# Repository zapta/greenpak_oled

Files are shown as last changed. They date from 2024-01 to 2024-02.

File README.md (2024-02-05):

# Addressable SPI OLED display

This design demonstrates the technique of adding device addressing capabilities to a SPI bus. This provides the speed and distance of an SPI bus with the simplicity and extensibility of an I2C bus.

The addressability is achieved using a Renesas's GreenPAK SPLD devices which interprets the first byte of each SPI transaction as a meta control byte and passes the CS signal to the device only if the address encoded in the control byte matches the device's address. The supported OLED displays are 1.3" SSD1306 and SH1106. 

> **NOTE**: The SSD1306 and the SH1106 are compatible at the hardware level but require different software drivers.

Resources
* PCB schematic: https://github.com/zapta/greenpak_oled/blob/main/kicad/greenpak_oled.pdf
* GreenPAK design schematic: https://github.com/zapta/greenpak_oled/blob/main/greenpak/greenpak_oled.svg
* GreenPAK source and hex files: https://github.com/zapta/greenpak_oled/tree/main/greenpak
* Interactive BOM: https://htmlpreview.github.io/?https://github.com/zapta/greenpak_oled/blob/main/kicad/bom/ibom.html

<br>

Components side:

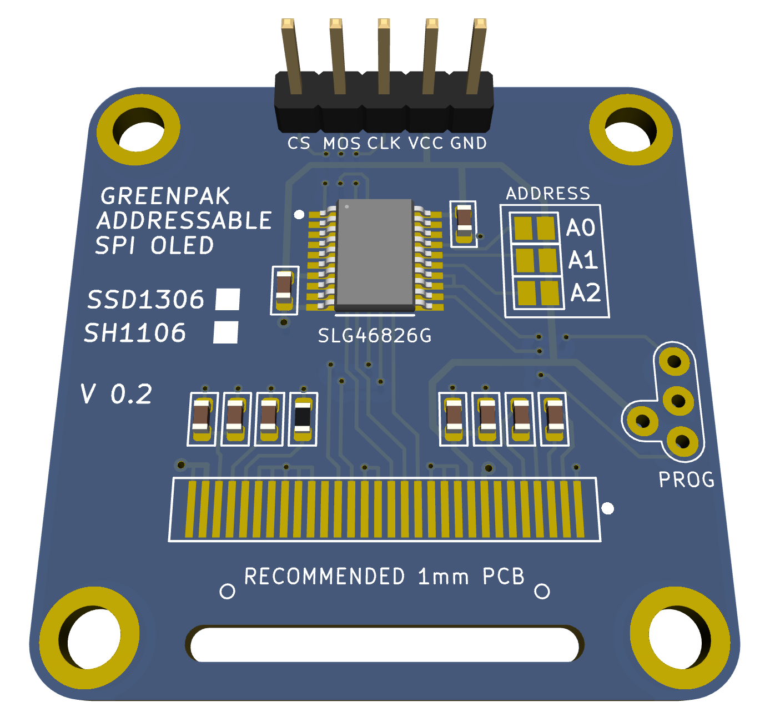
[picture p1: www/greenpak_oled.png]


<br>

Display panel side:

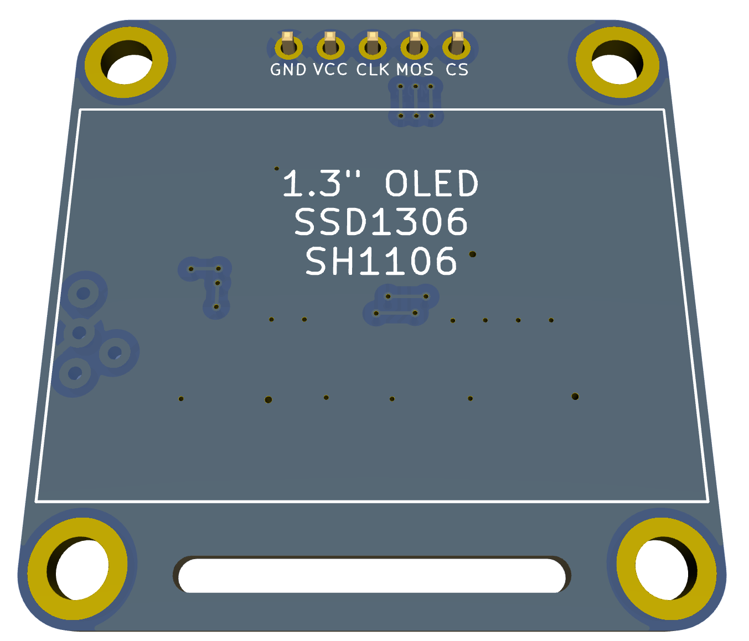
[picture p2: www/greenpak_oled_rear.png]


<br>

Wiring diagram (for oled_demo.py):

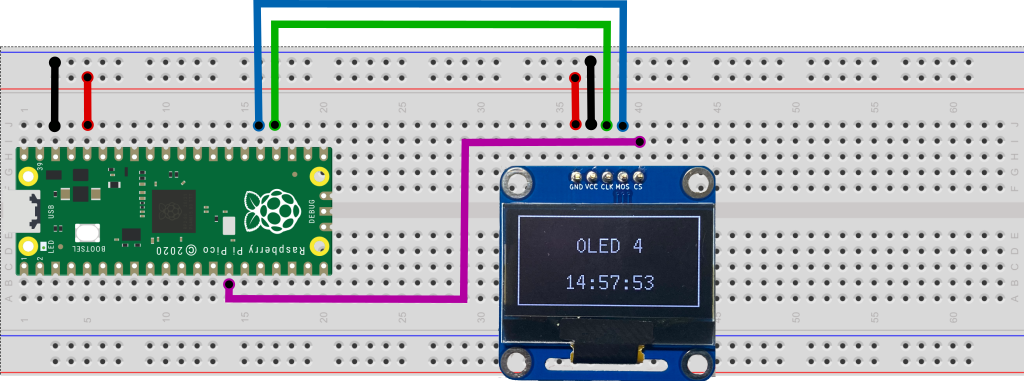
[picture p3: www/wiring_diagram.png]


## Protocol

A SPI transaction is a sequence of bytes transfer between a high-to-low and a low-to-high transitions of the ``CS`` signal. To tag a transaction with a device address, prepend to it a control byte which include the target device address as well as the desired states of the OLED ``RST`` and ``DC`` inputs.

| Bit field | Function | Description |
|---|---|---|
| Bits [7:5] |  Reserved | Set to 0. |
| Bits [4:4] |  RST | The value of the OLED RST input. |
| Bits [3:4] |  DC | The value of the OLED D/C input  |
| Bits [2:1] |  Address | The target device address in the range [0, 7] |

The address of each device is set by its three solder jumbers, with an open jumper
representing ``0`` and short jumper representing ``1``

## Device SPI address

The device address is set by shorting with solder the necessary solder jumpers according to this table:

|Address | A1 | A1 | A0 |
|:---:|:---:|:---:|:----:|
| 0 |  - |  - |  - |
| 1 |  - |  - |  Solder |
| 2 |  - | Solder | -  |
| 3 |  - | Solder | Solder  |
| 4 | Solder |  - | -  |
| 5 | Solder |  - |  Solder |
| 6 | Solder | Soler | -  |
| 7 | Solder | Solder | Solder  |

## oled_demo.py

The Python program demo_oled.py demonstrates the addressability by continuously writing a different content to each of the eight possible device addresses. Connecting one or more 
device will display on each a number that identify it's address. The demo uses a USB to SPI adapter, such as a plain Raspberry Pi Pico, that is compatible with the  Python package ``spi-adapter``.

## Timing diagrams

The screenshot below shows a typical address enabled SPI transaction. The first byte 
is the control byte ``0x12`` contains the signals ``OLED_RST=1``, ``OLED_DC=0``, and is ``ADDRESS=2``, and is matched against the device address, which happens to be 2,  and causes a match. This sets the ``OLED_RST`` and ``OLED_DC`` outputs to their respective values (no change in the case of ``OLED_RST``) and then enables ``OLED_CS`` such that the rest of the bytes are processed by the OLED device.

<br>

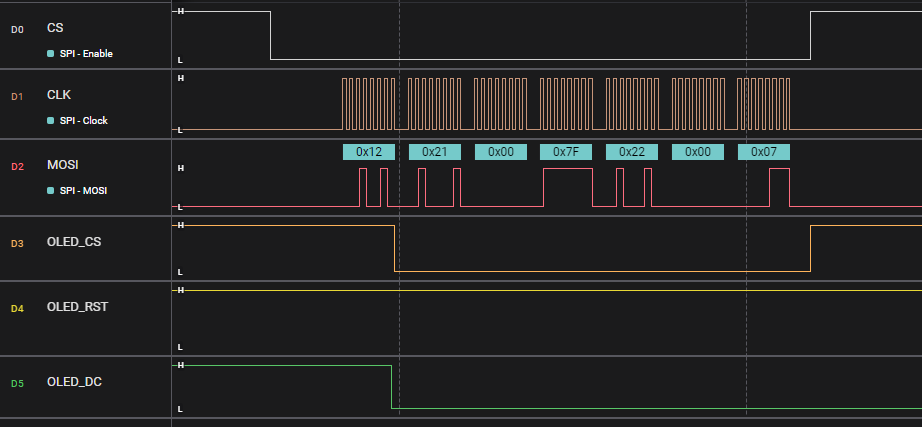
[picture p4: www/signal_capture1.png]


The following diagram zoom on the control byte. Note that the ``OLED_DC`` (and so ``OLED_RST`` when changed) stabilizes on its new level before  ``OLED_CS`` is asserted low.

<br>

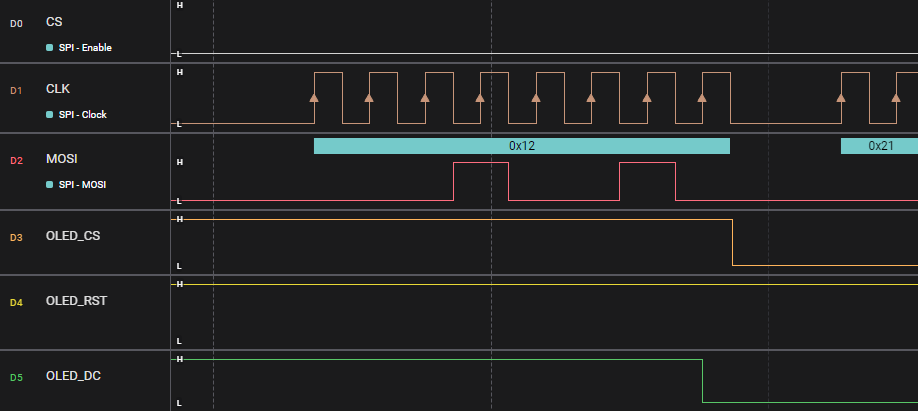
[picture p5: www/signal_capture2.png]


## How it works?

The diagram below shows the main functional blocks of the GreenPAK design. For full details and the latest version, explore the design file ``greenpak_oled.gp6`` file using the Renesas design tool.

1. I2C programming support. Used only for flashing or reflashing the GreenPAK device and is not used in normal operation.
2. Serial to parallel shifter. A shift register that provides the four previous SPI bit values.
3. First byte detector. Generates signal that indicates the time of the 8'th bit of the control byte (the first byte in the SPI transaction)
4. Address matcher. On the last bit of the control byte, tests if the address matches.
5. OLED_CS generator. A latch that generates the the ``OLED_CS`` output signals.
6. Auxiliary signals generators. Latches for the ``OLED_RST`` and ``OLED_DC`` output signals.
  
<br>



## Making your own

To make your own Addressable SPI OLED display follow these steps:

1. Order the PCB and components.
1. Assemble the components, including the OLED panel which is soldered to the 30 pags strip.
1. Program the GreenPAK device as described below.
1. Set the display address on the SPI bus by soldering the necessary solder jumpers.

The Github repository contains an HTML interactive BOM that helps identifying the components and their values.

## Flashing the GreenPAK

Flashing the GreenPAK IC can be done in-circuit via the programming pads which are compatible with the [GreenPAK Pogo Probe](https://github.com/zapta/greenpak_pogo). The provided Python program ``flasher.py`` allows to program it using an USB to I2C adapter such as the Raspberry Pi Pico, or the Sparkfun Pro Micro RP2040. which are supported by the Python ``i2c_adapter`` package. 

## FAQ

Q: What is the operating voltage of the OLED display.

A: 3.3V nominal.

---

Q: What SPI mode is used?

A: SPI mode 0 as required by the SSD1306 and SH1106 controllers.

---

Q: What SPI speeds are supported?

A: We tested it successfully with 4Mhz SPI clock.

---

Q: Why only 3 address jumpers?

A: We run out of resources in the GreenPAK device. 

---

Q: I want to change the design of the GreenPAK device, what tools do I need?

A: The Go Configure tool is available for free from Renesas and it allows to edit and test GreenPAK designs.  https://www.renesas.com/us/en/software-tool/go-configure-software-hub

---

Q: Why GreenPAK?

A: They are inexpensive, stand alone, flexible, have a small footprint, not requiring glue components.

---

Q: What kind of a guarantee do you provide with this design?

A: None whatsoever, the design is provided 'as-is'.

---

Q: This design doesn't uses MISO. Is it possible have MISO reading with addressable SPI?

A: Yes. A MISO signal can be used without having to change the GreenPAK's design.

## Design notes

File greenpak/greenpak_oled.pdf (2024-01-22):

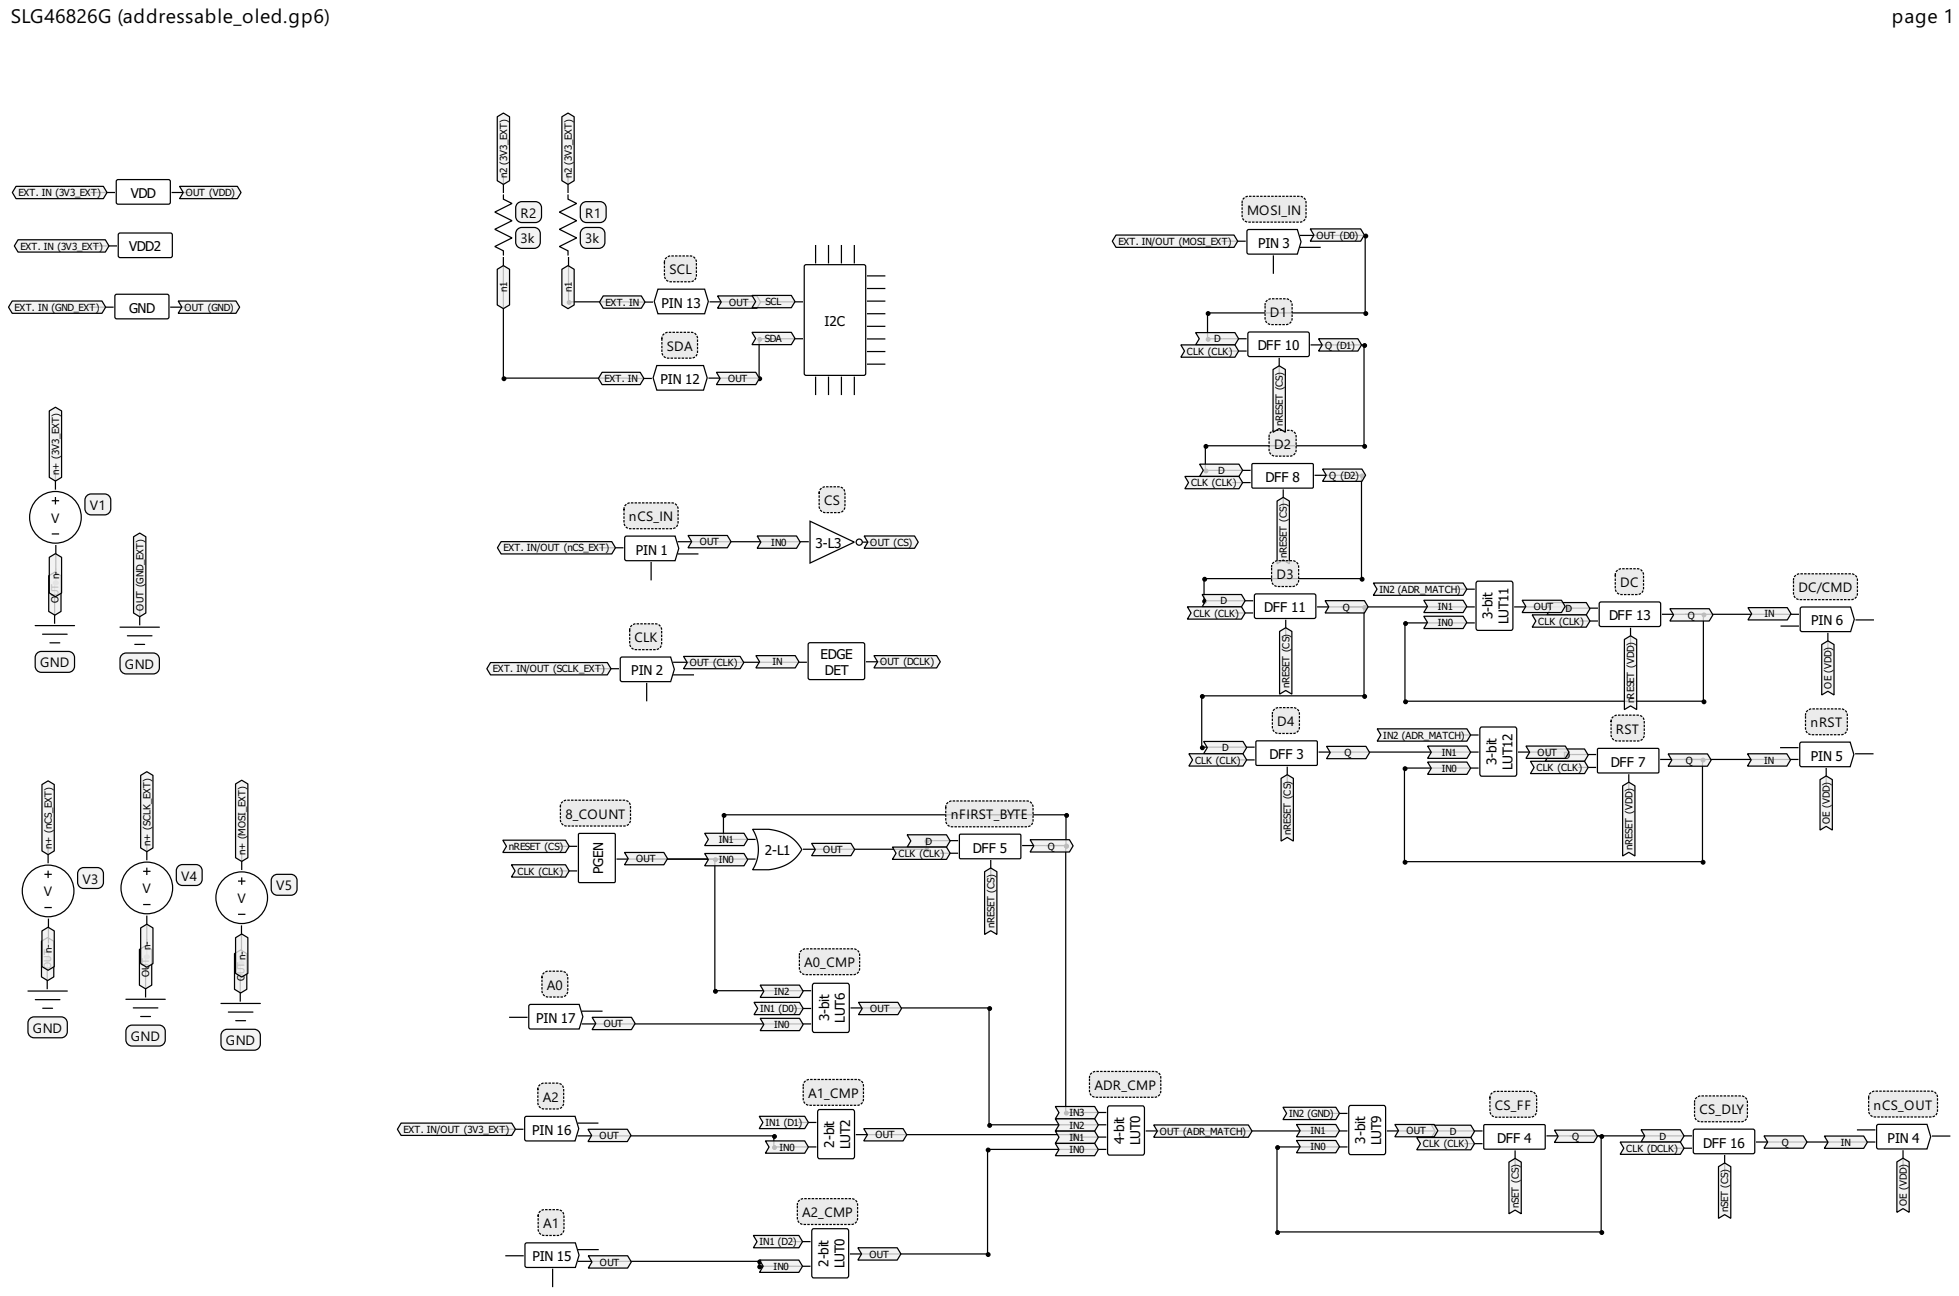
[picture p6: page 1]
SLG46826G (addressable_oled.gp6); page 1; EXT. IN; PIN 13; OUT; SCL; SDA; PIN 12; EXT. IN (GND_EXT); GND; OUT (GND); EXT. IN (3V3_EXT); VDD2; VDD; OUT (VDD); OUT PIN 17; EXT. IN/OUT (3V3_EXT); PIN 16; OUT PIN 15; OE (VDD); PIN 6; DC/CMD; PIN 5; nRST; PIN 4; nCS_OUT; OUT (D0) EXT. IN/OUT (MOSI_EXT); PIN 3; MOSI_IN; OUT (CLK) EXT. IN/OUT (SCLK_EXT); PIN 2; CLK; EXT. IN/OUT (nCS_EXT); PIN 1; nCS_IN; OUT (DCLK) EDGE; DET; OUT 2⁻bit; LUT0; A2_CMP; LUT2; A1_CMP; nRESET (CS); CLK (CLK); PGEN; 8_COUNT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
P rty rop e | Va l u e
alu Min. v e ( V) | 3.1 0

Ty
p. v

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
x. v

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
P rop e rty | l Va u
| Digital input In mode Digital in with Schmit e I/O selection

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
ull D
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
P rop e rty | l Va u
e I/O selection | Digital input In mode | Digital in with Schmit

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
ull D
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
P rop e rty | l Va u
| Digital input In mode Digital in with Schmit e I/O selection

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
ull D
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
e I/O selection | Digital input In mode | Digital in without Sch

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
P rop e rty | l Va u
e I/O selection | Digital input In mode | Digital in without Sch

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
P rty rop e | Va l u e
alu Min. v e ( V) | 3.1 0
Ty alu ( V) p. v e | 3.3 0

M
a
x. v

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
e I/O selection | Digital output In mode | None Out mode | 1x push pull PIN 5 (IO10) Label: "nRST" Property | Value I/O selection | Digital output In mode | None Out mode | 1x push pull | P

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
e I/O selection | Digital output In mode | None Out mode | 1x push pull PIN 3 (IO12) Label: "MOSI_IN" Property | Value I/O selection | Digital input In mode | Digital in with Schmit

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
ull D
o

w

n
R sis t alu e o r v e | 1 0 0 K

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
P rop e rty | l Va u
e I/O selection | Digital input In mode | Digital in with Schmit

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
ull D
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
P rop e rty | l Va u
e I/O selection | Digital input In mode | Digital in with Schmit

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
ull U
p
R sis t alu e o r v e | 1 0 0 K
1 0 0 u A p ullu p o n in p u t | Dis a ble

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
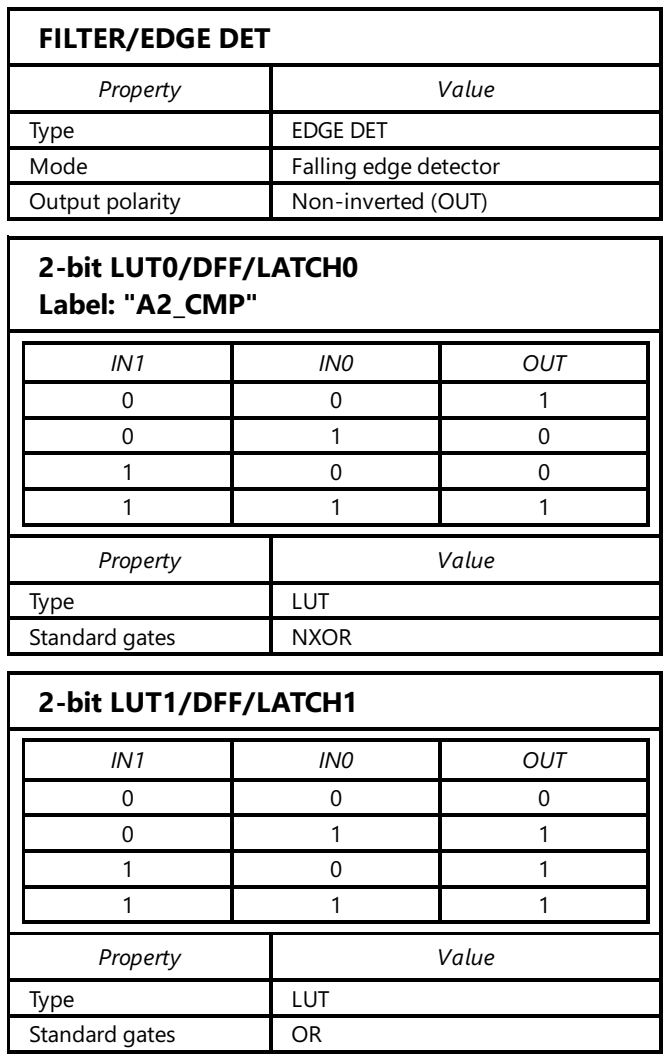
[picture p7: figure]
P rty rop e; allin; ola rit y; ATC H; rop; rty; P rop e rty

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
### ATC

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
P rop e rty | Va l u e
Ty p e | L U T

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
6 : 0

P t t a e r n | 0 0 0 0 0 0 1

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
### ATC

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
P rop e rty | l Va u e

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
d ele S e c o n Q s c t | f fir Q o s t D F F

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
T Initial polarity | Low Q output polarity | Non-in

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
### ATC

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
P rty rop e | Va l u e

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
T Initial polarity | High Q output polarity | Non-in

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
### ATC

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
M d o e | D F F
S E T/ R E S E T tio n n o p n | R E S E n
| Low Q output polarity Non-in T Initial polarity

d v e r t e ( Q)

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
### ATC

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
I N 0 | O U T
0 | 1
1 | 0
P rop e rty | Va l u e

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
s | In
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
### ATC

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
P rop e rty | l Va u e
Ty p e | D F F / L ATC H
M o d e | D F F
n S E T/ n R E S E T o p tio n | n R E S E
| Low Q output polarity Non-in T Initial polarity
| t Q) v

### 3-bit LUT5/DFF/LATCH8 Label: "D2"

Property | Value
Type | DFF / LATCH
Mode | DFF
nSET/nRESET option | nRESET
Initial polarity | Low
Q output polarity | Non-inverted (Q)

### 3-bit LUT6/Pipe Delay/Ripple Counter Label: "A0_CMP"

IN2 | IN1 | IN0 | OUT
0 | 0 | 0 | 0
0 | 0 | 1 | 0
0 | 1 | 0 | 0
0 | 1 | 1 | 0
1 | 0 | 0 | 1
1 | 0 | 1 | 0
1 | 1 | 0 | 1
1 | 1 | 1 | 0
Property | Value
Type | LUT
Standard gates | Defined by user

### MF0 (4-bit LUT0, DFF/LATCH9, WS Ctrl, 16-bit CNT0/DLY0/FSM0)

### 4-bit LUT0 (MF0) Label: "ADR_CMP"

IN3 | IN2 | IN1 | IN0 | OUT
0 | 0 | 0 | 0 | 0
0 | 0 | 0 | 1 | 0
0 | 0 | 1 | 0 | 0
0 | 0 | 1 | 1 | 0
0 | 1 | 0 | 0 | 0
0 | 1 | 0 | 1 | 0
0 | 1 | 1 | 0 | 0
0 | 1 | 1 | 1 | 1
1 | 0 | 0 | 0 | 0
1 | 0 | 0 | 1 | 0
1 | 0 | 1 | 0 | 0
1 | 0 | 1 | 1 | 0
1 | 1 | 0 | 0 | 0
1 | 1 | 0 | 1 | 0
1 | 1 | 1 | 0 | 0
1 | 1 | 1 | 1 | 0
Property | Value
Standard gates | Defined by user

### MF1 (3-bit LUT7, DFF/LATCH10, 8-bit CNT1/ DLY1)

### DFF/LATCH10 (MF1) Label: "D1"

Property | Value
Mode | DFF
nSET/nRESET option | nRESET
Initial polarity | Low
Q output polarity | Non-inverted (Q)

### MF2 (3-bit LUT8, DFF/LATCH11, 8-bit CNT2/ DLY2)

### DFF/LATCH11 (MF2) Label: "D3"

Property | Value
Mode | DFF
nSET/nRESET option | nRESET
Initial polarity | Low
Q output polarity | | Non-inverted (Q)

### MF3 (3-bit LUT9, DFF/LATCH12, 8-bit CNT3/ DLY3)

### 3-bit LUT9 (MF3)

IN2 | IN1 | IN0 | OUT
0 | 0 | 0 | 0
0 | 0 | 1 | 1
0 | 1 | 0 | 0
0 | 1 | 1 | 0
1 | 0 | 0 | 0
1 | 0 | 1 | 1
1 | 1 | 0 | 0
1 | 1 | 1 | 0
Property | Value
Standard gates | Defined by user

### MF4 (3-bit LUT10, DFF/LATCH13, 8-bit CNT4/ DLY4)

### DFF/LATCH13 (MF4) Label: "DC"

Property | Value
Mode | DFF
nSET/nRESET option | nRESET
Initial polarity | Low
Q output polarity | Non-inverted (Q)
SLG46826G (addressable_oled.gp6) | page 4

### MF5 (3-bit LUT11, DFF/LATCH14, 8-bit CNT5/ DLY5)

### 3-bit LUT11 (MF5)

IN2 | IN1 | IN0 | OUT
0 | 0 | 0 | 0
0 | 0 | 1 | 1
0 | 1 | 0 | 0
0 | 1 | 1 | 1
1 | 0 | 0 | 0
1 | 0 | 1 | 0
1 | 1 | 0 | 1
1 | 1 | 1 | 1
Property | Value
Standard gates | Defined by user

### MF6 (3-bit LUT12, DFF/LATCH15, 8-bit CNT6/ DLY6)

### 3-bit LUT12 (MF6)

IN2 | IN1 | IN0 | OUT
0 | 0 | 0 | 0
0 | 0 | 1 | 1
0 | 1 | 0 | 0
0 | 1 | 1 | 1
1 | 0 | 0 | 0
1 | 0 | 1 | 0
1 | 1 | 0 | 1
1 | 1 | 1 | 1
Property | Value
Standard gates | Defined by user

### MF7 (3-bit LUT13, DFF/LATCH16, 8-bit CNT7/ DLY7)

### DFF/LATCH16 (MF7) Label: "CS_DLY"

Property | Value
Mode | DFF
nSET/nRESET option | nSET
Initial polarity | High
Q output polarity | Non-inverted (Q)

I2C

Property | Value
IO Latching | Enable
Mode selection | Standard/fast mode
Control code, bin | 0001
Control byte, read/ write | 0x11 / 0x10

Device address, dec/
hex

8 / 0x08

PIN 19 (IO0) output
expander select

From matrix

PIN 14 (IO5) output expander select | From matrix
PIN 11 (IO6) output expander select | From matrix
PIN 6 (IO9) output expander select | From matrix
Virtual OUT0 | 0
Virtual OUT1 | 0
Virtual OUT2 | 0
Virtual OUT3 | 0
Virtual OUT4 | 0
Virtual OUT5 | 0
Virtual OUT6 | 0
Virtual OUT7 | 0
PIN 19 (IO0) OUT | 0
PIN 14 (IO5) OUT | 0
PIN 11 (IO6) OUT | 0
PIN 6 (IO9) OUT | 0

Control code selection
#3 | #2 | #1 | #0

0 | 0 | 0 | 1
SLG46826G (addressable_oled.gp6) | page 5

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
Volt
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
s Internal capacitance | 10
0 n
F Internal resistance | 10Ohm Pre-start state | Low Type | DC DC Voltage | 3.3V Ramp rise time | 1ms V3 Property

Va

l
u

e

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
p la
s

t
s

t
a

t
e
Ty p e | L gic o p a t t e r n
M d o e | N o r m
| 3.3V Umin 0V Levels adjustment Standar al Umax
| d
Ris tim e e | 1 μ s
F all tim e | 1 μ s

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
2 5 0 μ s | 3.3 V
2 5 0 μ s | 0 V

2
5

0
μ

s

3.3
V
2 5 0 μ s | 0 V
2 5 0 μ s | 3.3 V
2 5 0 μ s | 0 V

2
5

0
μ

s

3.3
V
2 5 0 μ s | 0 V
2 5 0 μ s | 3.3 V

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
2 5 0 μ s | 0 V
2 5 0 μ s | 3.3 V
2 5 0 μ s | 0 V
2 5 0 μ s | 3.3 V
2 5 0 μ s | 0 V
2 5 0 μ s | 3.3 V
2 5 0 μ s | 0 V
2 5 0 μ s | 3.3 V

2
5

0
μ

s

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
D u ra t i o n | l Vo t a g e
5 0 0 μ s | 3.3 V
5 0 0 μ s | 0 V
5 0 0 μ s | 0 V
5 0 0 μ s | 3.3 V
5 0 0 μ s | 3.3 V
5 0 0 μ s | 0 V
5 0 0 μ s | 3.3 V
5 0 0 μ s | 0 V
5 0 0 μ s | 0 V
5 0 0 μ s | 3.3 V
5 0 0 μ s | 3.3 V
5 0 0 μ s | 3.3 V
5 0 0 μ s | 0 V
5 0 0 μ s | 3.3 V
5 0 0 μ s | 3.3 V

P

oj
c

t
c

M

i
n. | Typ. | M
a
x. VDD (V): | 3.10 | 3.30 | 3.40 VDD2 (V): | 3.10 | 3.30 | 3.40 Temperature (°C): | 25.00 | 25.00 | 25.00 General Settings GPIO quick charge | Disable Pattern ID | 1 2k Register lock status | Unlocked 2k NVM lock status | Unlocked Emulated EEPROM lock status | Unlocked Protect entire lock configuration | Disable

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
X: 0
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
C: 1

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
X: 0
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
C: 1

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
X: 0
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
C: 1

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
X: 0
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
C: 1

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
X: 0
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
C: 1

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
X: 0
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
C: 1

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
X: 0
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
C: 1

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
X: 0
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
C: 1

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
X: 0
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
C: 1

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
X: 0
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
C: 1

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
X: 0
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
C: 1

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
X: 0
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
C: 1

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
X: 0
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
C: 1

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
X: 0
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
C: 1

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
X: 0
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
C: 1

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
X: 0
x

`
b
D

E

C: 1

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
X: 0
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
C: 1

1
8

`
b
0

+

2 bit L U T 3 / P G E N --> O U T | N E T 2 8 | H E X: 0 7 6 ` b 1 x D E C: 1 1 8 ` b 1 | +
3 bit L U T 0/ D F F / -L ATC H 3 Q -> | N E T 3 5 | H E X: 0 7 6 ` b 2 x D E C: 1 1 8 ` b 2 | +
3 bit L U T 1 / D F F / -L ATC H 4 Q -> | C S O U T n _ | H E X: 0 7 6 ` b 3 x D E C: 1 1 8 ` b 3 | +
3 bit L U T 2 / D F F / -L ATC H 5 Q -> | N E T 2 9 | H E X: 0 7 6 ` b 4 x D E C: 1 1 8 ` b 4 | +
3 bit L U T 3 / D F F / -L ATC H 6 O U T -> | C S | H E X: 0 7 6 ` b 5 x D E C: 1 1 8 ` b 5 | +
3 bit L U T 4/ D F F / -L ATC H 7 Q -> | N E T 3 4 | H E X: 0 7 6 ` b 6 x D E C: 1 1 8 ` b 6 | +
3 bit L U T 5 / D F F / -L ATC H 8 Q -> | D 2 | H E X: 0 7 6 ` b 7 x D E C: 1 1 8 ` b 7 | +
3 bit L U T 6/ Pip -e D ela / Rip ple C t y o u n e r -> O U T | N E T 2 3 | H E X: 0 7 7 ` b 0 x D E C: 1 1 9 ` b 0 | +
3 bit L U T 6/ Pip -e D ela y / Rip ple C o u n t e r -> Q 1 | | H E X: 0 7 7 ` b 1 x D E C: 1 1 9 ` b 1 | -
3 -bit L U T 6/ Pip e ela ple D y / Rip C o u n t e r Q 2 -> | | H E X: 0 x 7 7 ` b 2 ` b D E C: 1 1 9 2 | -
FILT E R/ E D G E D E T -> O U T | D C L K | ` b H E X: 0 x 7 7 3 D E C: 1 1 9 ` b 3 | +
P D LY -> O U T | | ` b H E X: 0 x 7 7 4 D E C: 1 1 9 ` b 4 | -
bit 8 -C N T 1 / D LY 1 ( M F 1 ) O U T -> | | ` b H E X: 0 x 7 7 5 D E C: 1 1 9 ` b 5 | -
O S C 1 -> O U T 0 | | ` b H E X: 0 x 7 7 6 D E C: 1 1 9 ` b 6 | -
O C -> O U T | | ` b H E X: 0 x | -

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
C: 1

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
X: 0
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
C: 1
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
X: 0
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
C: 1
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
X: 0
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
C: 1
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
X: 0
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
C: 1
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
X: 0
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
C: 1
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
X: 0
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
C: 1
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
X: 0
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
C: 1
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
X: 0
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
C: 1
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
X: 0
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
C: 1
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
X: 0
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
C: 1
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
X: 0
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
C: 1
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
X: 0
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
C: 1
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
X: 0
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
C: 1
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
X: 0
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
C: 1
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
X: 0
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
C: 1
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
X: 0
x

`
b
D

E

C: 1

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
s I2C -> OUT7

H

E

X: 0
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
C: 1
2

2

`
b
0
- I2C -> OUT6 | HEX: 0x7A`b1 DEC: 122`b1 | - I2C -> OUT5 | HEX: 0x7A`b2 DEC: 122`b2 | - I2C -> OUT4 | HEX: 0x7A`b3 DEC: 122`b3 | - I2C -> OUT3 | HEX: 0x7A`b4 DEC: 122`b4 | - I2C -> OUT2 | HEX: 0x7A`b5 DEC: 122`b5 | - I2C -> OUT1 | HEX: 0x7A`b6 DEC: 122`b6 | - I2C -> OUT0 | HEX: 0x7A`b7 DEC: 122`b7 | -
A C M P 0 H O U T -> | | H E X: 0 7 B ` b 0 x D E C: 1 2 3 ` b 0 | -
A C M P 1 H O U T -> | | H E X: 0 7 B ` b 1 x D E C: 1 2 3 ` b 1 | -
A C M P 2 L O U T -> | | H E X: 0 7 B ` b 2 x D E C: 1 2 3 ` b 2 | -
A C M P 3 L O U T -> | | H E X: 0 7 B ` b 3 x D E C: 1 2 3 ` b 3 | -
O S C 1 O U T 1 -> | | H E X: 0 7 B ` b 4 x D E C: 1 2 3 ` b 4 | -
O S C 0 O U T 1 -> | | H E X: 0 7 B ` b 5 x D E C: 1 2 3 ` b 5 | -
P O R O U T -> | | H E X: 0 7 B ` b 6 x D E C: 1 2 3 ` b 6 | -
V D D ( PIN 2 0 ) O U T -> | V D D | H E X: 0 7 B ` b 7 x D E C: 1 2 3 ` b 7 | +

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
bit 1 6 -C N T 0/ D LY 0/ F S M 0 ( M F 0 ) | d C o u n t e D a t a | H E X: 0 x 7 C , 0 x 7 D D E C: 1 2 4 1 2 5 ,
bit 8 -C N T 2 / D LY 2 ( M F 2 ) | d C o u n t e D a t a | H E X: 0 x 7 E D E C: 126
bit 8 -C N T 4/ D LY 4 ( M F 4 ) | d C o u n t e D a t a | H E X: 0 x 7 F D E C: 127

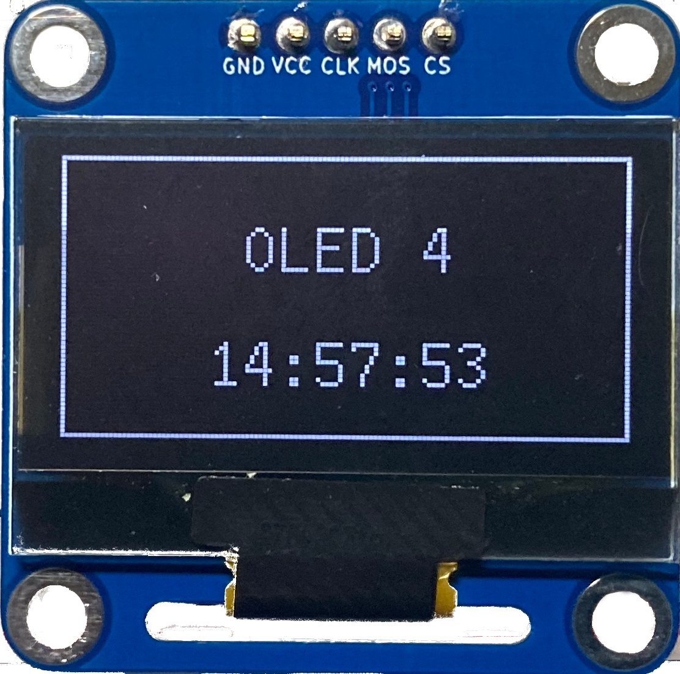
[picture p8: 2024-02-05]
www/spi_oled_pic.png

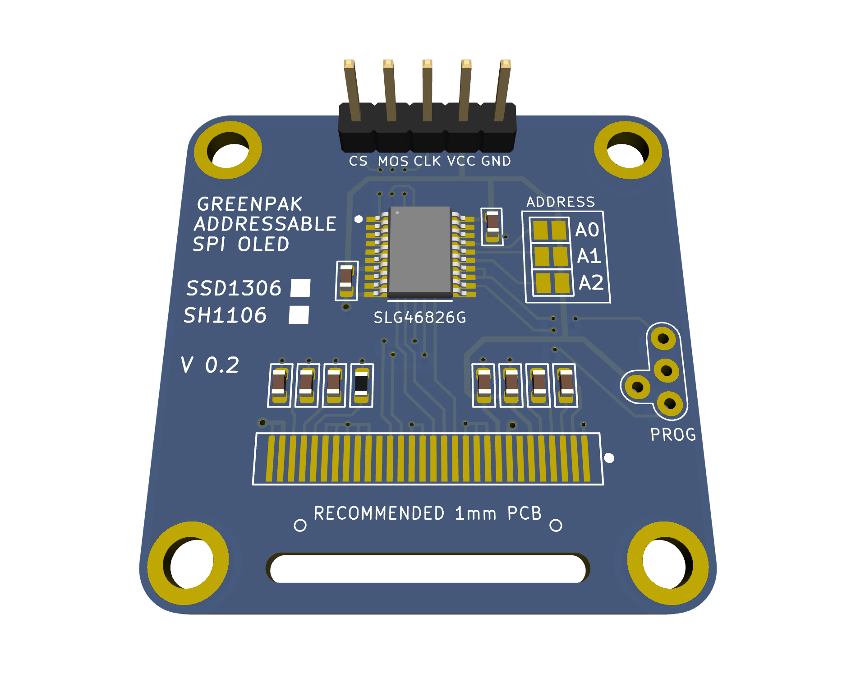
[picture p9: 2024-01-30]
kicad/greenpak_oled.png

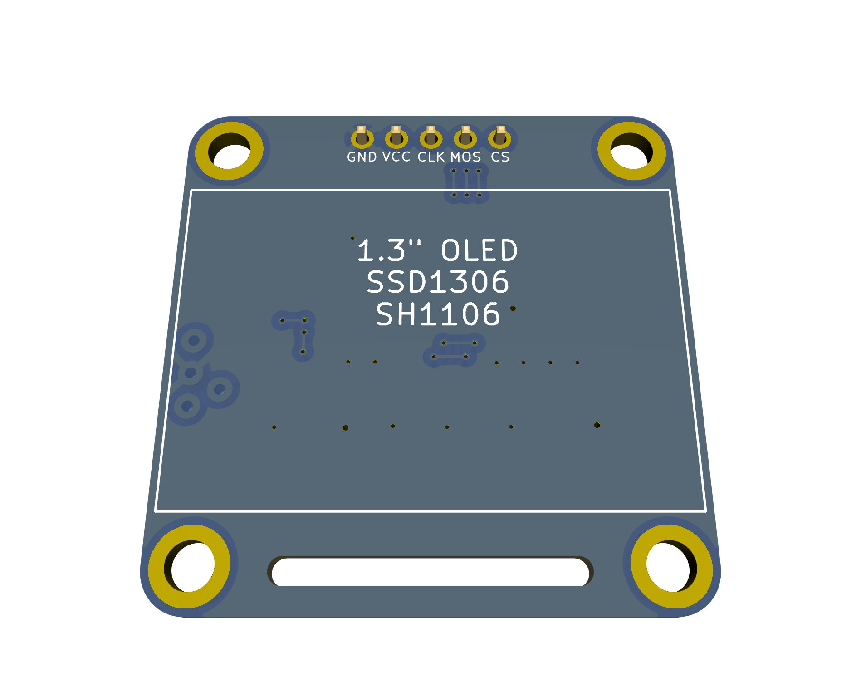
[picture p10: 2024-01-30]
kicad/greenpak_oled_rear.png

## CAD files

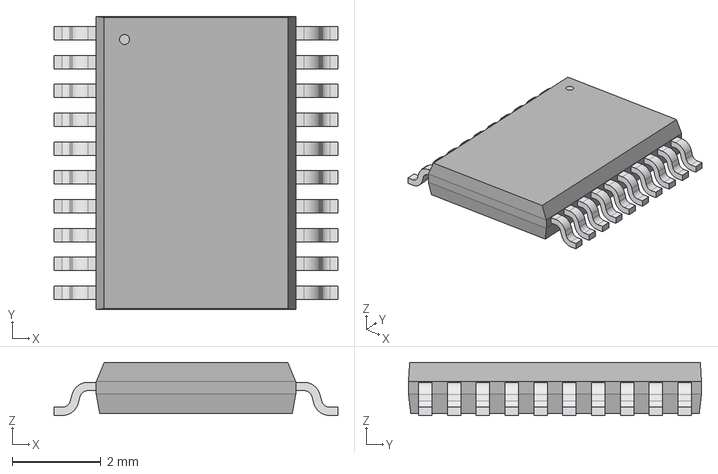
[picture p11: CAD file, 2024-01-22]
kicad/3d_models/TSSOP20_MO-220_WECE_REN.step
6.40 x 6.60 x 1.20 mm

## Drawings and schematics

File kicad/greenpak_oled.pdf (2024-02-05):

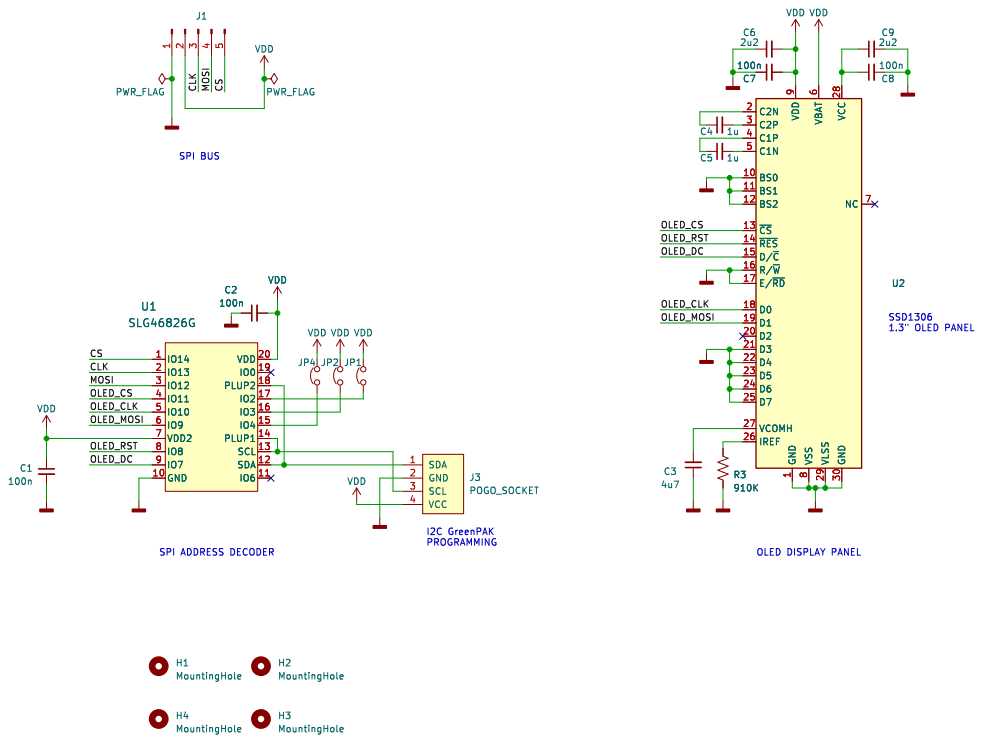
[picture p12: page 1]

1.3" OLED PANEL SPI ADDRESS DECODER U1 SLG46826G

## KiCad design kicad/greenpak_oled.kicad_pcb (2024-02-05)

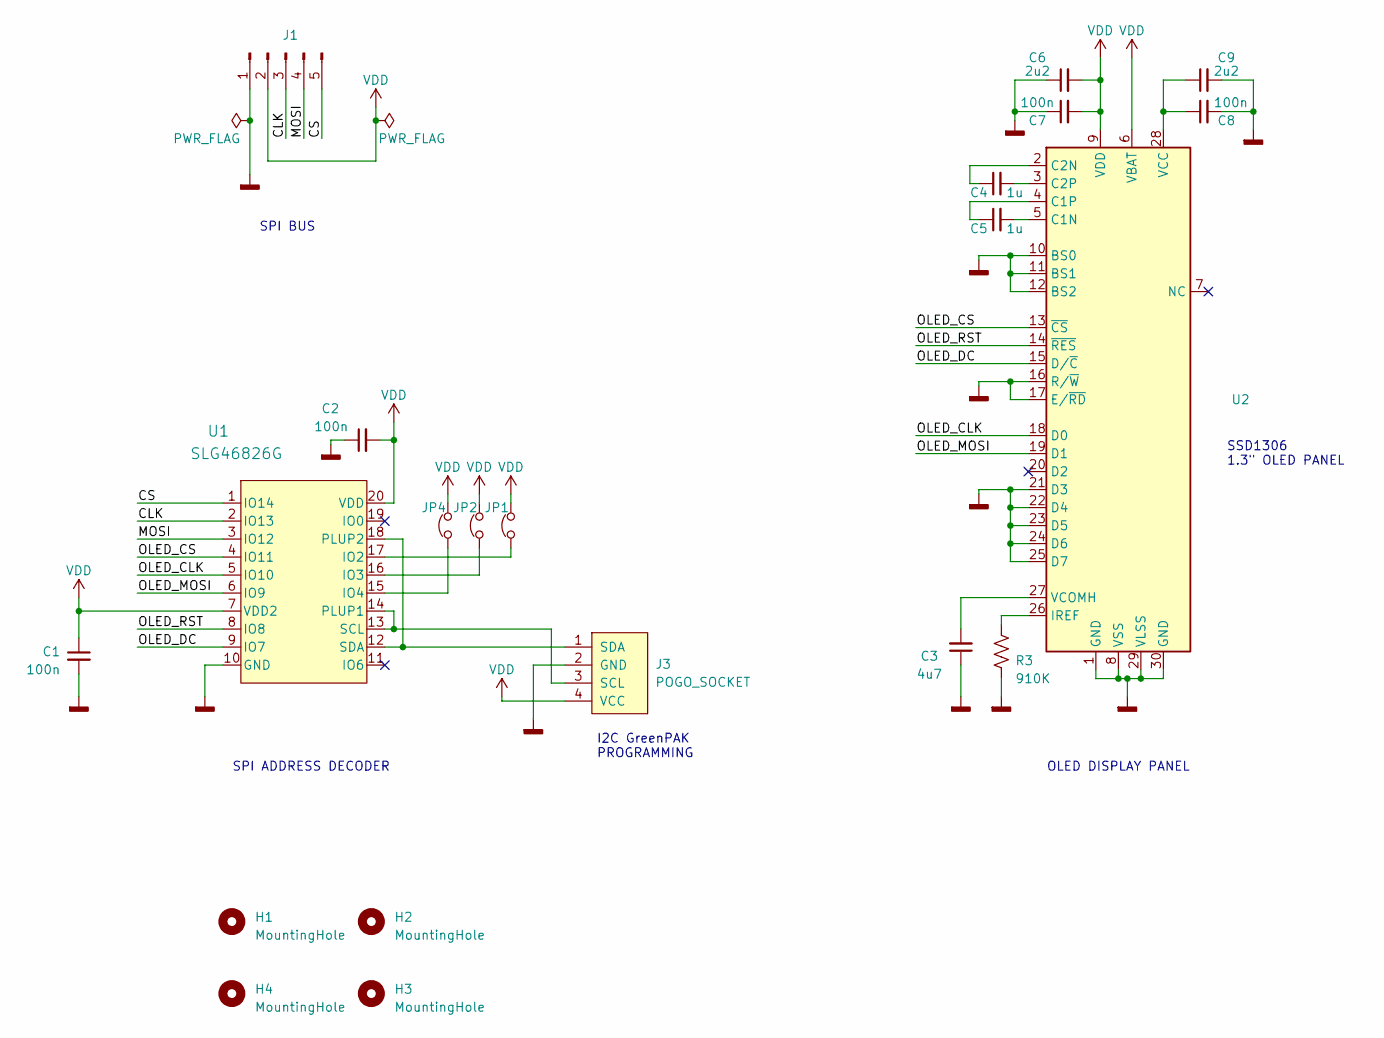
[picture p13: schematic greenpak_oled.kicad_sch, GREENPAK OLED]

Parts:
C1, C2, C7, C8: 100n; C_0603_1608Metric
C3: 4u7; C_0603_1608Metric
C4, C5: 1u; C_0603_1608Metric
C6, C9: 2u2; C_0603_1608Metric
H1, H2, H3, H4: MountingHole
J1: Conn_01x05_Pin; PinHeader_1x05_P2.54mm_Vertical
J3: POGO_SOCKET; GREENPAK_POGO_SOCKET
JP1, JP2, JP4: Jumper_2_Open; SolderJumper-2_P1.3mm_Open_Pad1.0x1.5mm
R3: 910K; R_0603_1608Metric
U1: SLG46826G; TSSOP20_MO-220_WECE_REN
U2: OLED-128O064D

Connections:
/CLK: J1.3, U1.2 (IO13)
/CS: J1.5, U1.1 (IO14)
/MOSI: J1.4, U1.3 (IO12)
/OLED_CLK: U1.5 (IO10), U2.18 (D0)
/OLED_CS: U1.4 (IO11), U2.13 (~CS)
/OLED_DC: U1.9 (IO7), U2.15 (D/~C)
/OLED_MOSI: U1.6 (IO9), U2.19 (D1)
/OLED_RST: U1.8 (IO8), U2.14 (~RES)
GND: C1.2, C2.1, C3.1, C6.1, C7.1, C8.2, C9.2, J1.1, J3.2 (GND), R3.2, U1.10 (GND), U2.1 (GND), U2.8 (VSS), U2.10 (BS0), U2.11 (BS1), U2.12 (BS2), U2.16 (R/~W), U2.17 (E/~RD), U2.21 (D3), U2.22 (D4), U2.23 (D5), U2.24 (D6), U2.25 (D7), U2.29 (VLSS), U2.30 (GND)
unnamed: J3.3 (SCL), U1.13 (SCL), U1.14 (PLUP1)
unnamed: J3.1 (SDA), U1.12 (SDA), U1.18 (PLUP2)
unnamed: JP1.1, U1.17 (IO2)
unnamed: JP2.1, U1.16 (IO3)
unnamed: JP4.1, U1.15 (IO4)
unnamed: C5.2, U2.5 (C1N)
unnamed: C5.1, U2.4 (C1P)
unnamed: C4.1, U2.2 (C2N)
unnamed: C4.2, U2.3 (C2P)
unnamed: R3.1, U2.26 (IREF)
unnamed: C8.1, C9.1, U2.28 (VCC)
unnamed: C3.2, U2.27 (VCOMH)
VDD: C1.1, C2.2, C6.2, C7.2, J1.2, J3.4 (VCC), JP1.2, JP2.2, JP4.2, U1.7 (VDD2), U1.20 (VDD), U2.6 (VBAT), U2.9 (VDD)

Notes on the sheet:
SSD1306 1.3" OLED PANEL
I2C GreenPAK PROGRAMMING
SPI BUS
OLED DISPLAY PANEL
SPI ADDRESS DECODER

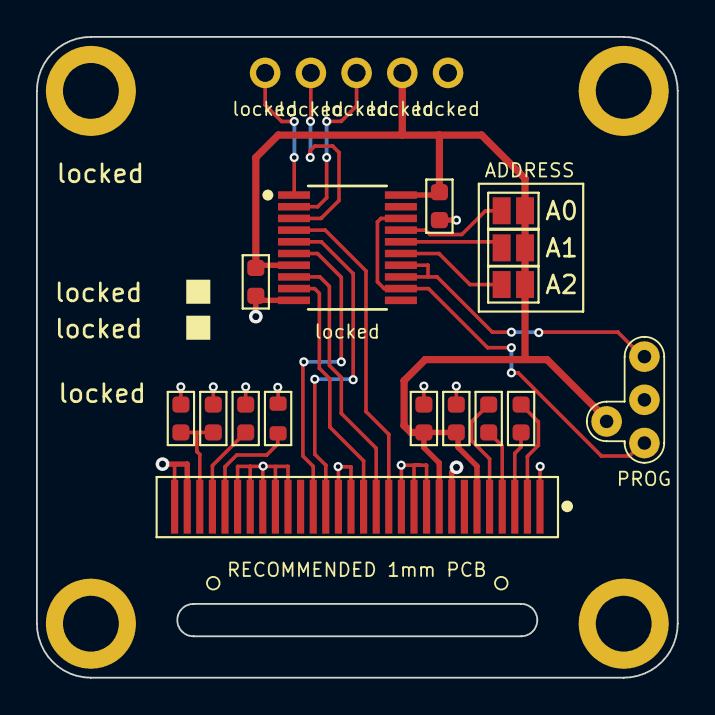
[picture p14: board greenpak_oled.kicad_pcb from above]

Board: 2 copper layers, 35.6 x 35.6 mm, 21 parts (0 on the bottom side), 22 nets.

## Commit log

2024-01-22 Copied kicad project to the new directory.
    [TSSOP20_MO-220_WECE_REN.step, greenpak_oled.kicad_pcb, greenpak_oled.kicad_sch]
2024-01-22 Renamed left over addressable_oled to greenpak_oled.
    [greenpak_oled.kicad_pcb, greenpak_oled.kicad_sch]
2024-01-22 Final touched. Regenerated gerbers.
    [greenpak_oled.kicad_pcb, greenpak_oled.kicad_sch]
2024-01-23 Updated pcb rendering.
2024-01-23 Fixed a typo in the silkscreen
    [greenpak_oled.kicad_pcb]
2024-01-23 Added an annotated GreenPAK schematic.
2024-01-23 Changed programming pads to pogo socket.
    [greenpak_oled.kicad_pcb, greenpak_oled.kicad_sch]
2024-01-24 Increased the size of the POGO socket.
    [greenpak_oled.kicad_pcb]
2024-01-24 Added a reference to the GreenPAK Pogo Probe.
2024-01-24 Tweaked the schematic to match also SH1106.
    [greenpak_oled.kicad_pcb, greenpak_oled.kicad_sch]
2024-01-24 Changed the PCB to have a slot instead of a cut.
    [greenpak_oled.kicad_pcb]
2024-01-24 Tweaked the flex cable slot.
    [greenpak_oled.kicad_pcb]
2024-01-24 Tweaked layout. Regenerated gerbers.
    [greenpak_oled.kicad_pcb]
2024-01-24 Added a link to the interactive BOM.
2024-01-24 Tweaked the interactive bom comment.
2024-01-27 Removed unused schematic symbol.
2024-02-05 Added wiring diagram.
2024-02-05 Integrated the wiring diagram in README.md
2024-02-05 Updated pogo socket dimensions.
    [greenpak_oled.kicad_pcb, greenpak_oled.kicad_sch]
2024-02-05 Updated programming socket, adjusted flex cable slot, generated gerbers 03.
    [greenpak_oled.kicad_pcb, greenpak_oled.kicad_sch]
